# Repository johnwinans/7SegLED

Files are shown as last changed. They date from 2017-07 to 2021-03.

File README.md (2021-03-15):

# 7SegLED
A back &amp; diffuser for a giant 3D printed 7-segment LED

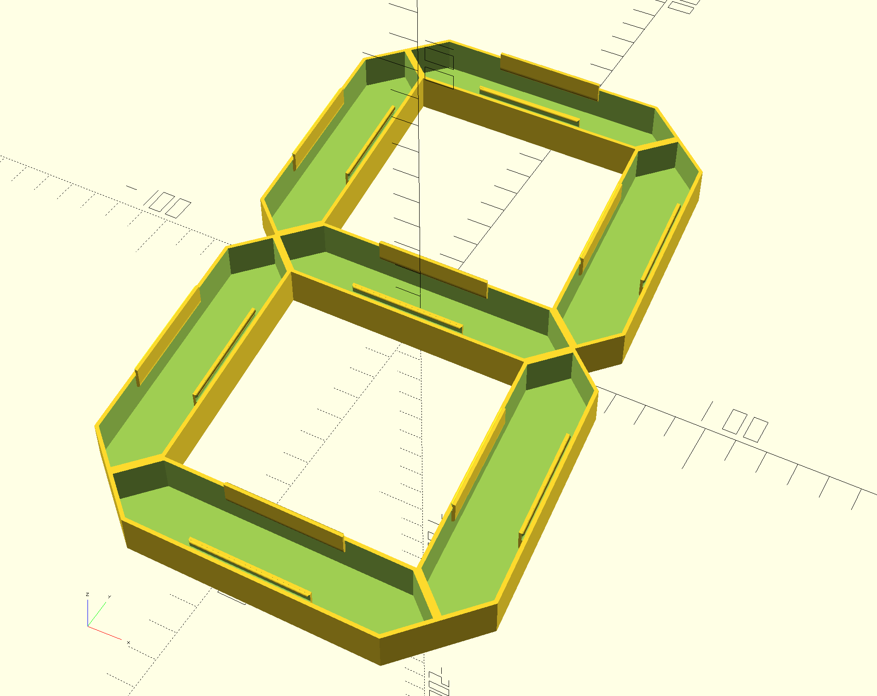
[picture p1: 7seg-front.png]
250mm front diffuser


This repo is a companion site for this YouTube playlist:

https://www.youtube.com/watch?v=XcRvE1MVENI&list=PL3by7evD3F52WPUhJhPRLl_CtDEd7zmzj

NOTE:  This repo includes a git-tag (what Github calls a 'release') such that the tag names
match the parts/episodes of the video series.  v1.2 is the code at the completion of part-2
of the video series.  v1.3 is code at the completion of part 3 and so on.  You can find a 
zip file for each of these tags by clicking on Github's 'releases' tab for this repo.

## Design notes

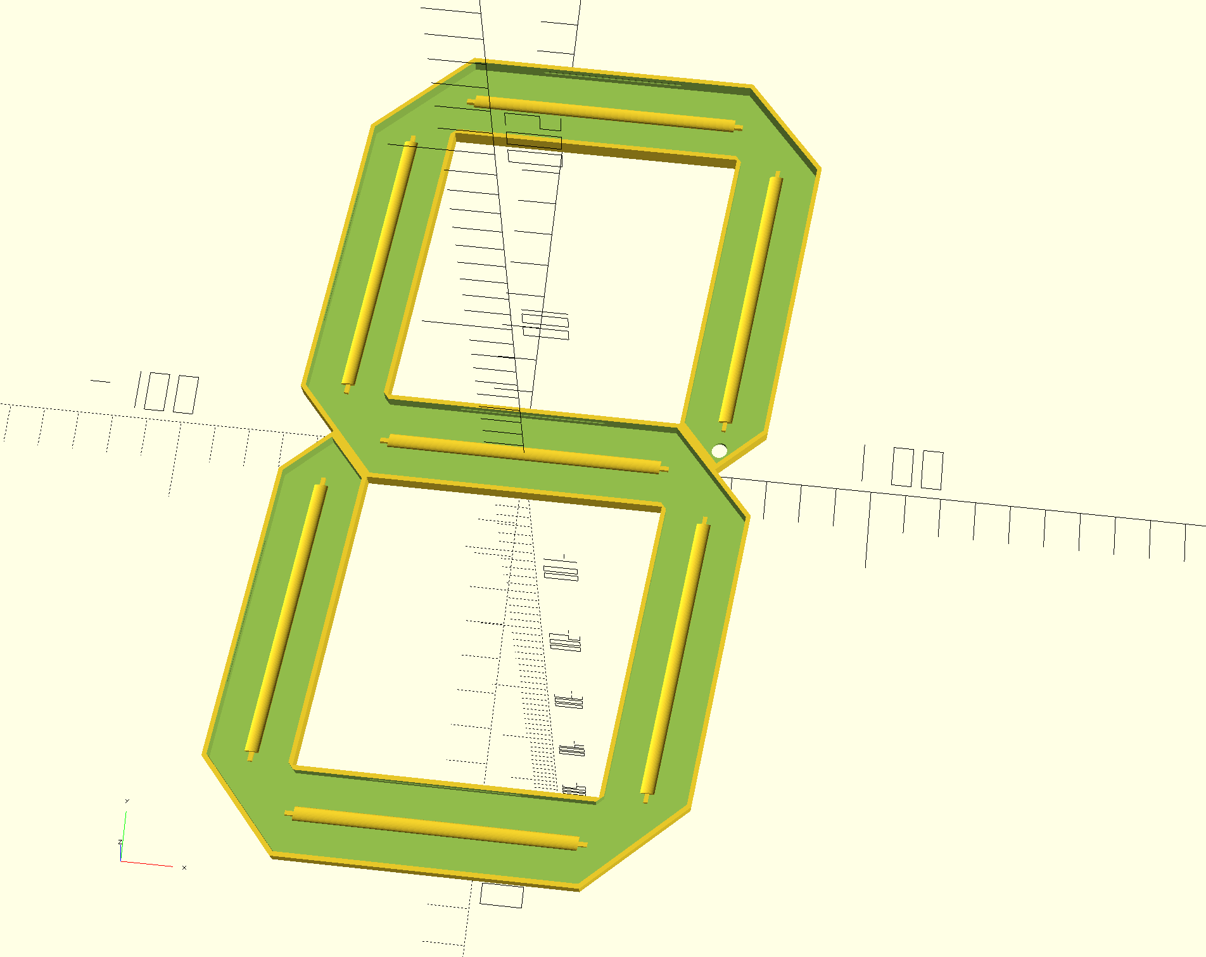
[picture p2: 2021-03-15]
7seg-back.png

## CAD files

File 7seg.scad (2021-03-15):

// ****************************************************************************
//
//    7SegLED - a 3D printable 7-segment LED
//
//    Copyright (C) 2017 John Winans
//
//    This program is free software: you can redistribute it and/or modify
//    it under the terms of the GNU General Public License as published by
//    the Free Software Foundation, either version 3 of the License, or
//    (at your option) any later version.
//
//    This program is distributed in the hope that it will be useful,
//    but WITHOUT ANY WARRANTY; without even the implied warranty of
//    MERCHANTABILITY or FITNESS FOR A PARTICULAR PURPOSE.  See the
//    GNU General Public License for more details.
//
//    You should have received a copy of the GNU General Public License
//    along with this program. If not, see <http://www.gnu.org/licenses/>.
//
//
//    Get your copy from here:
//
//       https://github.com/johnwinans/7SegLED
//       
// ****************************************************************************

include <skew.scad>

ledLen=100/6;           // length of each LED in the strip
ledWidth=10;            // width of one LED strip
wallThickness=1.3;      // the thickness of the segment side-walls
dividerWidth=1.2;       // the width of the strip-divider
dividerHeight=1.5;      // the height of the strip-divider
slotWidth=ledWidth+.75; // the width of the slot needed for an LED strip
segNumLedStrips=2;      // how many LED strips per segment
segNumStripLeds=5;      // how many LEDs per strip
wireHoleSize=4.5;

segInsideWidth = segNumLedStrips*slotWidth+(segNumLedStrips-1)*dividerWidth;   // gross segment inside width
segOutsideWidth = segInsideWidth+2*wallThickness; // gross segment outside width

segInsideLength = segNumStripLeds*ledLen;         // inside length (w/o end-caps)
segOutsideLength = segInsideLength+2*(tan(45/2)*wallThickness);   // outside length (w/o end-caps)

segBackThickness=1.2;   // The thickness of the back
segBackDepth=5;         // How deep to make the LED strip slots
segFrontThickness=1.2;  // The thickness of the front (face of the diffuser)
segFrontDepth=13;       // how deep to make the front

segGrossBackZ = segBackDepth+segBackThickness;    // Gross Z-height of the back
segGrossFrontZ = segFrontDepth+segFrontThickness; // Gross Z-height of the front 



// Uncomment ONE of the following lines to render either the front or back
//skew([6,0,0,0,0,0]) back7();
//skew([6,0,0,0,0,0]) back7Top();
//skew([6,0,0,0,0,0]) back7Bottom();

skew([-6,0,0,0,0,0]) front7();
//skew([-6,0,0,0,0,0]) front7Top();
//skew([-6,0,0,0,0,0]) front7Bottom();

//skew([-6,0,0,0,0,0]) front();
//skew([6,0,0,0,0,0]) back();



/**
* One complete 7-segment front/diffuser.
************************************************************************/
module front7()
{
    front7Top();
    front7Bottom();
}

module front7Top()
{
    rotate([0,0,90]) front();
    translate([0,(segOutsideLength+segOutsideWidth),0]) rotate([0,0,90]) front();
    translate([-(segOutsideLength/2+segOutsideWidth/2)+.0001,(segOutsideLength/2+segOutsideWidth/2),0]) front();
    translate([(segOutsideLength/2+segOutsideWidth/2)-.0001,(segOutsideLength/2+segOutsideWidth/2),0]) front();  
}

module front7Bottom()
{
    translate([0,-(segOutsideLength+segOutsideWidth),0]) rotate([0,0,90]) front();
    translate([-(segOutsideLength/2+segOutsideWidth/2)+.0001,-(segOutsideLength/2+segOutsideWidth/2),0]) front();
        translate([(segOutsideLength/2+segOutsideWidth/2)-.0001,-(segOutsideLength/2+segOutsideWidth/2),0]) front();
}

/**
* One complete 7-segment back.
************************************************************************/
module back7()
{
    back7Top();
    back7Bottom();
}

module back7Top()
{
    rotate([0,0,90]) back(ur=false, ll=false);
    translate([0,(segOutsideLength+segOutsideWidth),0]) rotate([0,0,90]) back(ul=false, ll=false);
    
    translate([-(segOutsideLength/2+segOutsideWidth/2)+.0001,(segOutsideLength/2+segOutsideWidth/2),0]) back(ur=false, lr=false);
    translate([(segOutsideLength/2+segOutsideWidth/2)-.0001,(segOutsideLength/2+segOutsideWidth/2),0]) back(ul=false, wireHole=true);
}

module back7Bottom()
{
    translate([0,-(segOutsideLength+segOutsideWidth),0]) rotate([0,0,90]) back(ur=false, lr=false);
    
    translate([-(segOutsideLength/2+segOutsideWidth/2)+.0001,-(segOutsideLength/2+segOutsideWidth/2),0]) rotate([0,0,180]) back(ul=false, wireHole=(segNumLedStrips%2==1));
        translate([(segOutsideLength/2+segOutsideWidth/2)-.0001,-(segOutsideLength/2+segOutsideWidth/2),0]) back(ul=false, ll=false);
}




/**
* One complete front/diffuser segment.
************************************************************************/
module front()
{
    segment(segInsideWidth, segInsideLength, 
        segOutsideWidth, segOutsideLength, 
        segFrontThickness, segFrontDepth,
        tongue=true);
}


/**
* One complete back segment.
*
* @param wireHole When true, include a hole in the bottom of the segment.
************************************************************************/
module back(ll=true, ul=true, lr=true, ur=true, wireHole=false)
{
    segment(segInsideWidth, segInsideLength, 
        segOutsideWidth, segOutsideLength, 
        segBackThickness, segGrossBackZ,
        groove=true,
        ll=ll, ul=ul, lr=lr, ur=ur, wireHole=wireHole);
    
    for ( x = [-segInsideWidth/2+slotWidth+dividerWidth/2 : slotWidth+dividerWidth : segInsideWidth/2] )
    {
        translate([x,0,dividerHeight/2+segBackThickness]) cube([dividerWidth, segInsideLength, dividerHeight], center=true);
        translate([x,0,dividerHeight+segBackThickness]) scale([1,1,.5]) rotate([90,0,0]) cylinder(d=4, h=segInsideLength-ledLen*.3, center=true, $fn=30);
    }
}
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

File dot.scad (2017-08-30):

//***************************************************************************
//
//    COPYRIGHT (C) 2017 JOHN WINANS
//
//    This program is free software: you can redistribute it and/or modify
//    it under the terms of the GNU General Public License as published by
//    the Free Software Foundation, either version 3 of the License, or
//    (at your option) any later version.
//
//    This program is distributed in the hope that it will be useful,
//    but WITHOUT ANY WARRANTY; without even the implied warranty of
//    MERCHANTABILITY or FITNESS FOR A PARTICULAR PURPOSE.  See the
//    GNU General Public License for more details.
//
//    You should have received a copy of the GNU General Public License
//    along with this program.  If not, see <http://www.gnu.org/licenses/>.
//
//    Get your copy from here:
//
//       https://github.com/johnwinans/7SegLED
//
//***************************************************************************

iDia=23;            // the inside diameter of the dot
wallthick=2;        // the outside wall thickness of the dot
backz=1;            // the thickness of the base
facez=1;            // the thickness of the face
hollowzb=5;         // the 'hollow' inside depth of the back
hollowzf=13;        // the 'hollow' inside depth of the front

ledff=.5;           // a fudge-factor for the LED dimensions
ledlen=100/6;       // length of one LED on the strip
ledwidth=10;        // width of the LED strip (not including the fudge factor)

$fa=1;              // select a reasonable resolution
$fs=.7;             // select a reasonable resolution


// uncomment one of the following to render a front or back:
back();             // render the back
//front();            // render the front




module front()
{
    dot(iDia, wallthick, hollowzf, facez, tongue=true);
}

module back()
{
    dot(iDia, wallthick, hollowzb, backz, groove=true, access=true, align=true);
}

/**
* Render a dot with optional tongue, groove and/or LED strip retainer.
*
* @param id The inside diameter of the dot cylinder
* @param wt The outter-wall thickness of the dot
* @param iz The inside Z-dimension (how much it is to be hollowed out)
* @param bz The face/back Z-dimension (how thick the face or back is to be)
* @param tongue If true then include a snap-together tongue
* @param groove If true then include a groove for the tongue to snap into
* @param access If true then include an access hole for wires
* @param align If true include a retainer to hold the LED strip
*****************************************************************************/
module dot(id, wt, iz, bz, tongue=false, groove=false, access=false, align=false)
{
    od=id+2*wt;     // outside diameter of the dot
    oz=iz+bz;       // Z-height of the dot (not including an optional tongue)

    tff=.2;         // printing fudge-factor for tongue allowance
    tzff=.5;        // extra height added to the groove slot so tongue will fit
    tod=id-tff*2;   // OD of the tongue
    tid=tod-2*wt;   // ID of the tongue
    tlen=3;         // z-height of the tongue
    tlipz=1;        // z-height of the lip
    tlipx=1;        // how far the lip sticks out from the tongue in the x-axis
    tzoverlap=wt;   // how far the tongue overlaps the 'inside' of the dot cylinder
 
    accessDia=5;    // access hole diameter (for wires)
    
    alignz=1;       // how tall the LED alignment box is
    alignwt=1.3;    // how thick the walls of the LED alignment box are
    retainz=1;      // the height of the retainer
    retainff=.5;    // how far to cover the LED with the retainer
    
    difference()
    {
        cylinder(d=od, h=oz);           // the main outer body of the dot
        translate([0,0,oz-iz]) cylinder(d=id, h=iz+.1); // remove the inside space (make it hollow)

        if (groove)
        {
            // a groove around the inside of the back to let the front sanap into the back
            translate([0,0,oz-tlen-tzff]) cylinder(d=id+tlipx, h=tlipz+tzff*2);
        }

        if (access)
        {
            // a hole for wire access
            translate([id/2-accessDia/2, 0,-.1]) cylinder(d=accessDia, h=bz+.2);
        }
    }

    
    if (align)
    {
        // some lines to align the LED strip against the back
        translate([0, 0, bz+alignz/2-.01])
        difference()
        {
            cube ([ledwidth+ledff+alignwt*2, ledlen+ledff+alignwt*2, alignz+.01], center=true);
            cube ([ledwidth+ledff, ledlen+ledff, alignz+.02], center=true);
        }
        
        // a retaining lip along the top
        translate([0, 0, bz+alignz+retainz/2-.01])
        difference()
        {
            cube ([ledwidth+ledff+alignwt*2, ledlen-3, retainz], center=true);
            cube ([ledwidth-retainff, ledlen-3+.02, retainz+.02], center=true);
        }
    }

    
    if (tongue)
    {
        intersection()
        {
            union()
            {
                // the tongue
                translate([0,0,oz-tzoverlap])
                difference()
                {
                    union()
                    {
                        cylinder(d=tod, h=tlen+tzoverlap);      // outside
                        cylinder(d=od, h=tzoverlap);            // fill the tff gap
                    }
                    translate([0,0,-.1])
                    {
                        cylinder(d=tid, h=tlen+tzoverlap+.2);   // remove the inside
                        cylinder(d1=id, d2=tid, h=tzoverlap);   // put a wedge on the bottom (easier printing)
                    }
                }
        
                // a rim around the tip of the tongue
                translate([0,0,oz+tlen-tlipz])
                {
                    difference()
                    {
                        cylinder(d=tod+.7, h=tlipz);                    // the rim
                        translate([0,0,-.1]) cylinder(d=tid, h=tlipz+.2);   // hollow out the rim cylinder
                    }
                }
        
            } // union
            
            // remove some of the tongue so that it only has two ends
            translate([-od/2,-od/6,oz-tzoverlap-.01]) cube([od, od/3, oz+tlen+tzoverlap+.02]);
            
        } // intersection
    }
}

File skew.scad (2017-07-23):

/**
* A utility function to skew an object.
*
* Taken from https://gist.github.com/boredzo/fde487c724a40a26fa9c
* Peter Hosey (boredzo)
* As amended by ziggy90127 
*
* skew takes an array of six angles:
* x along y
* x along z
* y along x
* y along z
* z along x
* z along y
***************************************************************************/
module skew(dims) 
{
    matrix = [
        [ 1, tan(dims[0]), tan(dims[1]), 0 ],
        [ tan(dims[2]), 1, tan(dims[3]), 0 ],
        [ tan(dims[4]), tan(dims[5]), 1, 0 ],
        [ 0, 0, 0, 1 ]
    ];
    multmatrix(matrix) children();
}

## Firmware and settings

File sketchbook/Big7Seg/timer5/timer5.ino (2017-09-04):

//***************************************************************************
//
//    7-Segment LED counter/timer sign.
//
//
//    COPYRIGHT (C) 2017 JOHN WINANS
//
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
//    Get your copy from here:
//
//       https://github.com/johnwinans/7SegLED
//
//***************************************************************************

/** @file
*
* This is a simple test app that controls a single-digit on a 7-segment display
* that is build using 2-LED NeoPixel strips.
*
* Arduino I/O configuration:
*
* - D6 = LED strip DI (Data In)
* .
************************************************************************************/

/**
* 
* I/O configuration:
*
* D6 = LED strip DI (Data In)
*
************************************************************************************/

#include <Adafruit_NeoPixel.h>

#define LED_STRIP_PIN  (6)


/**
* A 7-segment LED descriptor used to identify its starting LED address and the
* number of LEDs in the digit.
*
* @warning Change the data types to uint16_t if you have more than 256 LEDs.
************************************************************************************/
struct ledSescriptor_t
{
  uint8_t    startingLedNumber;    // the address of the first LED in a digit
  uint8_t    numStrips;            // number of strips per segment
  uint8_t    ledsPerStrip;         // number of LEDs per strip
};

/**
* One descriptor for each LED in the sign
************************************************************************************/
struct ledSescriptor_t descriptors[] =
{
  {0, 1, 2},     // small 1/10th digit 
  {14 ,2, 5},    // seconds LSD
  {84, 2, 5},    // seconds MSD
  {156, 2, 5},   // minutes LSD
  {226, 2, 5}    // minutes MSD
};

static const uint8_t colon1 = 154;  // the address of the first colon LED
static const uint8_t colon2 = 155;  // the address of the second colon LED

#define NUM_LEDS  (296)  // sizeof(descriptors)/sizeof(descriptors[0]))

// Tell the NeoPixel library how many LEDs we will be using
static Adafruit_NeoPixel LEDstrip(NUM_LEDS, LED_STRIP_PIN, NEO_GRB + NEO_KHZ800);



static volatile uint32_t myclock = 0;  // The current 10HZ timer/counter value.


/**
* Initialize things.
*************************************************************************************/
void setup() 
{
  LEDstrip.begin();
  LEDstrip.show(); // No colors set yet.  So this will set all pixels to 'off'.

  // initialize serial communication (for debugging)
  //Serial.begin(115200);
  
  counterReset();
  
  initTimer();
}


/**
* Initialize timer-1 to operate in CTC mode to operate at 10HZ.
*************************************************************************************/
void initTimer()
{
  // Do a google search on: arduino timer1 interrupt example for more details on this.
  
  cli();                   // disable all interrupts
  
  TCCR1A = 0;
  TCCR1B = 0;
  TCNT1 = 0;
  OCR1A = 6249;            // compare match register 16MHz/256/10Hz - 1
  TCCR1B |= (1 << WGM12);  // CTC mode
  TCCR1B |= (1 << CS12);   // 256 prescaler
  TIMSK1 |= (1 << OCIE1A); // enable timer compare interrupt
  
  sei();                   // enable all interrupts
}


/**
* When timer-1 expires (10 times per second) this interrupt handler is called.
*************************************************************************************/
ISR(TIMER1_COMPA_vect) // timer compare interrupt service routine
{
  ++myclock;    // increment the clock counter
}




/** @brief The 'next' time to 'tick' the clock counter. */
static uint32_t next=0;    // the 'next' time to 'tick' the clock counter

/** @brief The number of 'ticks' since the system was started. */
static uint32_t ctr=0;     // the number of 'ticks' since the system was started


/**
* Reset the timer 'tick' and 'next' values, effectively restting the timer display.
*************************************************************************************/
void counterReset()
{
  next = 0;           // prime the counter logic to start immediately
  //ctr = 60L*60*10;    // one hour (need L else get a 32 bit int :-/
  ctr = 3*60*10;      // 3 minutes
  //ctr = 6*10;         // 6 seconds
}

/** @brief The brightness (luminosity) of the LEDs (0=black, 255=bright) */
#define LUMA  255
//#define LUMA  127
//#define LUMA  63

/** @brief A dash character code. */
#define DASH_CHARACTER  (16)

/** @brief The black color. */
static const uint32_t blackColor = Adafruit_NeoPixel::Color(0, 0, 0); 

/** @brief The black color used for timer EXPIRED indicator. */
static const uint32_t redColor = Adafruit_NeoPixel::Color(LUMA, 0, 0); 

/** @brief The foreground (on) color to use for the 2-strip LEDs. */
static const uint32_t fg2 = Adafruit_NeoPixel::Color(LUMA/4, LUMA/2, 0);
  
/** @brief The foreground (on) color to use for the 1-strip LEDs. */
static const uint32_t fg1 = Adafruit_NeoPixel::Color(LUMA/3, LUMA, 0);


/**
* @brief Main processing loop.
*
* If enough time has passed to update the display:
* - advance the counter
* - display the new value
* - calculate the time for the next timer-tick 
*
* @note The millis function will wrap around every 49 days.  So if you want to 
*  use it for longer than that period, you will want to change the logic used to
*  determine 100 milliseconds have passed.
*************************************************************************************/
void loop() 
{
  static const unsigned long tperiod=1;//100;    // millis per tick
  static uint32_t pattern = 0;

  //uint32_t now = millis();

  cli(); // disable all interrupts
  uint32_t now = myclock;        // Do this with IRQs off in case the assignment is not atomic!
  sei(); // enable all interrupts

  if (now >= next)
  {
    next = next+tperiod;

    if (ctr == 0)
    {
      // when the count is zero, display a special DONE pattern of red dashes
      ++pattern;

      if (pattern%2 != 0)
      {
        uint32_t color = (pattern/2)%8==0 ? blackColor : redColor;

        // show a bunch of dashes
        digit(DASH_CHARACTER, 4, color);
        digit(DASH_CHARACTER, 3, color);
        digit(DASH_CHARACTER, 2, color);
        digit(DASH_CHARACTER, 1, color);
        digit(DASH_CHARACTER, 0, blackColor);
        
        LEDstrip.setPixelColor(colon1, blackColor);    // turn on the colon dots
        LEDstrip.setPixelColor(colon2, blackColor);      
      }
    }
    else
    {
      --ctr;
      
      uint8_t t = ctr%10;
      uint8_t ss = (ctr/10)%60;
      uint8_t mm = (ctr/600)%60;
      
      digit(mm/10, 4, mm/10 ? fg2 : blackColor);  // blank the leading zero
      digit(mm%10, 3, fg2);
      digit(ss/10, 2, fg2);
      digit(ss%10, 1, fg2);
      digit(t, 0, fg1);
      
      LEDstrip.setPixelColor(colon1, fg1);    // turn on the colon dots
      LEDstrip.setPixelColor(colon2, fg1);      
    }
    LEDstrip.show();  // Flush the settings to the LEDs
  }
}


/**
* @brief A 7-Segment display 'font'.
*
* This is the font used to convert the values from 0-F into a displayable
* character on a 7-segment display.  There is one value for each character.
*
* The relationship of the font bit positions to the LED display segments:
*
@verbatim
   --1--
  |     |
  2     0
  |     |
   --3--
  |     |
  6     4
  |     |
   --5--
@endverbatim
*
* For example: In order to display the number '1', the #0 and #4 segments need to be
* turned on and the rest turned off.  Therefore the binary value 0010001 
* (hex 0x11) represents the segment values to display a '1'.
*
* The most significant bit is not used.
*************************************************************************************/
static const uint8_t font[] =
{
  0b01110111,  // 0
  0b00010001,  // 1
  0b01101011,  // 2
  0b00111011,  // 3
  0b00011101,  // 4
  0b00111110,  // 5
  0b01111110,  // 6
  0b00010011,  // 7
  0b01111111,  // 8
  0b00111111,  // 9
  0b01011111,  // A
  0b01111100,  // b
  0b01100110,  // C
  0b01111001,  // d
  0b01101110,  // E
  0b01001110,  // F
  0b00001000   // - (a dash symbol)
};



/**
* @brief Set the value for a digit.
*
* @param i The hex digit value to value to display
* @param place The place value (position) to display the digit
* @param c The color of the segment to use.
*
* @warning This supports 1 or 2 strips per LED.  Supprt for 3 or more strips
*  is left as a task for the reader.  Hint: add a loop to calculate the value
*  for 13-k by using the strip number.
*************************************************************************************/
void digit(uint8_t i, uint16_t place, uint32_t c)
{
  uint8_t v = font[i];  // which segments are to be lit for the given digit value
  uint16_t startingLed = descriptors[place].startingLedNumber;  // first LED in the digit's 7seg LED
  uint8_t lps = descriptors[place].ledsPerStrip;                // number of LEDs in each strip of the digit
  uint8_t ns = descriptors[place].numStrips;                    // number of strips in each segment of the digit
  
  for(uint8_t k=0; k<7; ++k)
  {
    seg(startingLed+k*lps, lps, v&0x01 ? c : blackColor);  // set to black or color depending on the font

    if (ns == 2)
      seg(startingLed+(13-k)*lps, lps , v&0x01 ? c : blackColor);
  
    v >>= 1;
  }
}


/**
* @brief A utility function to set the color of a sequence of LEDs.
*
* @param startingLed The first LED address to set.
* @param qty The total number of LEDs in the consecutive sequence to set.
* @param c The color value to which the LEDs will be set.
*************************************************************************************/
void seg(uint16_t startingLed, uint16_t qty, uint32_t c)
{
  uint16_t last = startingLed+qty;
  
  while (startingLed < last)
  {
    LEDstrip.setPixelColor(startingLed, c);
    ++startingLed;
  }
}

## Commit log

2017-07-23 Ignore .stl files
2017-07-23 A single-segment with LED divider/retainer.
    [7seg.scad]
2017-07-23 Render seven segments (rather than just one). Added skew.scad.
    [7seg.scad, skew.scad]
2017-07-23 Added wire-access holes.
    [7seg.scad]
2017-07-24 Added support for knowcking doen segment walls for inter-segment wiring.
    [7seg.scad]
2017-07-26 Added tongue and groove to make the front & back segments snap together.
    [7seg.scad]
2017-07-26 Added a comment about what lines to un-comment for rendering.
    [7seg.scad]
2017-07-29 Config to render a single-segment skewed back for test-printing.
    [7seg.scad]
2017-07-29 Refactor so can print a 7-seg LED larger than the printer bed.
    [7seg.scad]
2017-07-30 Added an Arduino sketchbook with the Adafruit_NeoPixel in it.
2017-08-30 Added a dot/semicolon app.
    [dot.scad]
2017-09-03 Added single-digit LED sign test app.
2017-09-04 Added first attempt at implementing a multi-digit count-down timer app.
2017-09-04 Change timing logic to use a custom 10HZ timer to improve accuracy.
2021-03-15 Configured for 250mm digits.
    [7seg.scad]
